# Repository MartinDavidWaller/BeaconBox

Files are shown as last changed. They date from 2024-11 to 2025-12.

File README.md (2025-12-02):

# BeaconBox - As published in Practical Wireless March 2025

BeaconBox - bringing life to the "YAESU THE RADIO AMATEUR's WORLD MAP"



## Modes

BeaconBox supports 3 three modes. The videos below demonstrate each one. 

### Beacons Heard Mode - Click on the image to launch the video.

(https://www.youtube.com/watch?v=FNRje14J34g)

### Beacons Active Mode - Click on the image to launch the video.

(https://www.youtube.com/watch?v=Vpn9oOLJUsw)

### Beacons In Daylight Mode - Click on the image to launch the video.

(https://www.youtube.com/watch?v=ngtQo7elz8o)

## Component list

Map and frame aside the following components will be required.

| Component | Quantity | Potential Source
| --- | --- | ---|
| Capacitor 100nf (104) | 24 |
| Capacitor 1nf | 1 |
| ESP32 WROOM-32 30 Pin | 1 | https://www.ebay.co.uk/itm/235648899105 See the image below. I have been sent some that simply say "ESP-32" on the top and they have failed. If you buy one from here and it does not say "ESP-MODULE-32" like the picture below I would return it. You should be able to see this before opening the protective wrapper.
| Misc' Hardware - Nuts & Bolts, PCB standoffs etc. These requirements will depend on your build. | * | 
| LED Holders 8mm | 18 | https://www.ebay.co.uk/itm/196322906972?var=496149156991
| PCB - Beacon LED Board | 18 |
| PCB - Frequencies Board | 1 |
| PCB - Processor Board | 1 |
| PCB Mount Terminal Block 3-Way | 2 |
| PCB Mount Terminal Block 2-Way | 2 | 
| Resistors 75 Ohm 1/4 Watt | 24 |
| Switch 6x6x5mm Momentary PCB Tactile | 2 |
| Wiring Loom | three different coloured wires, 3m of each | 
| WS2812D 8mm LEDs | 24 | https://www.ebay.co.uk/itm/134876658482

Not that the ESP32 WROON-32 30 Pin should look like:

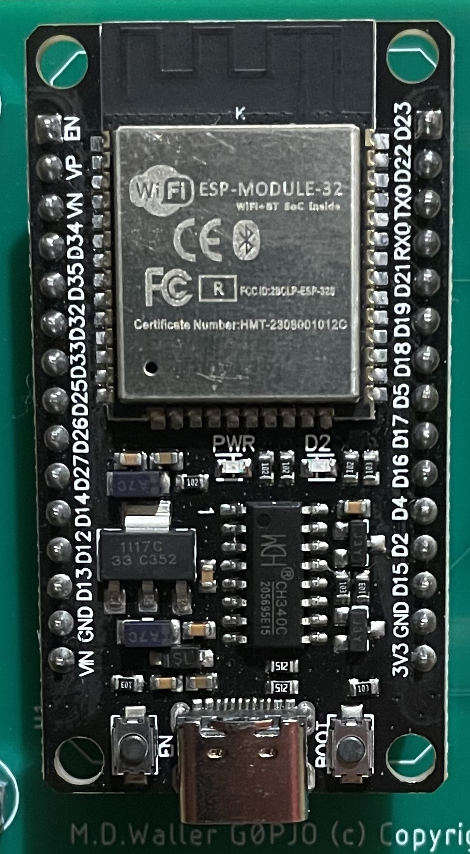
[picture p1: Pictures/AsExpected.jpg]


## Wiring the LEDs

The LEDS on the main board must be wired in the following order:

ZL6B, VK6RBP, JA2IGY, VR2B, 4S7B, RR90
4X6TU, 5Z4B, ZS6DN, OH2B, CS3B, VE8AT
W6WX, KH6RS, 4U1UN, YV5B, OA4B, and LU4AA

For more information about the 8mm LEDs see: https://www.electrokit.com/upload/product/41020/41020706/41020706.pdf

## Installing the software - See updates below

The source code for BeaconBox is not available. The software is distributed as a binary file
that can be downloaded directly to the ESP32 using esptool.exe that can be downloaded 
from https://github.com/espressif/esptool/releases. Download and install esptool.exe.

What follows is very specific to Microsoft Windows but similar tools and processes will apply
to MacOS etc.

Next connect the ESP32 to your computer using a USB cable. The device should appear as a COM port. 
You can use the Device Manager to identify thee new port - look for something called "USB-SERIAL CH340"
or similar. To be sure you have the correct COM port you could unplug it and see it dissapear and 
then plug it back in and see it appear. 

Next open a command window and type the command:

esptool.exe --chip esp32 --port COM4 --baud 921600 write_flash 0x0 BeaconBox_V0_8.bin

You may need to provide the complete path to the esptool.exe and you will probably need
to change COM4 to the COM port identified above.

## Issues

Please do not hesitate to contact me at martin@the-wallers.net is you have any problems.

## Updates

December 2nd, 2025 - Beacon_Box V0.8 Released

Changes

a) Update the help to specify tha a SPACE is needed between callsigns in the "Spotter Wildcards:".  
b) Fixed a bug where the updates of "Spotter Wildcards:" were not being acknowledged until the 
next reboot.

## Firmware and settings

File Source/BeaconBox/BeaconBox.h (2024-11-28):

/*
 *  BeaconBox.h
 *  
 *  Author:   M.D. Waller - G0PJO
 *  Copyright (c) 2024
 */

// The following manifests provide the product information

#define PROGRAM_NAME "BeaconBox"
#define PROGRAM_VERSION_MAJOR 0
#define PROGRAM_VERSION_MINOR 7
#define COPYRIGHT_TEXT "(C) M.D.Waller G0PJO"

// ----

#define REVERSE_BEACON_NETWORK_ADDRESS "telnet.reversebeacon.net"
#define REVERSE_BEACON_NETWORK_PORT 7000

#define DEFAULT_SPOTTER_WILDCARDS "G*"
#define DEFAULT_TIMEZONE "GMT0BST,M3.5.0/01,M10.5.0/02"

#define DEFAULT_SPOTTER_TIMEOUT_MINUTES 5
#define DEFAULT_FREQUENCY_STEP_TIME_SECONDS 5
#define DEFAULT_LED_BRIGHTNESS 255

// The mode pin must support pullout. See https://forum.arduino.cc/t/esp32-pins-that-support-pullup/1173356/3

#define MODE_PIN 25

// LEDs - two LED types are supported WS2812B and WS2812D (8mm)

#define LED_TYPE_WS2812B 1
#define LED_TYPE_WS2812D 2

// Supported Builds

#define BUILD_TYPE_TEST_BOARD 1
#define BUILD_TYPE_YAESU_MAP 2

#define BUILD_TYPE BUILD_TYPE_YAESU_MAP

#if BUILD_TYPE == BUILD_TYPE_TEST_BOARD

  #define LED_TYPE LED_TYPE_WS2812B
    
#elif BUILD_TYPE == BUILD_TYPE_YAESU_MAP

  #define LED_TYPE LED_TYPE_WS2812D
#else

  #error BUILD_TYPE - Unrecognised value.
#endif

// Define the animation defaults

#define DEFAULT_ANIMATION_ENABLED true
#define DEFAULT_ANIMATION_BEACONS_HEARD_DURATION_SECONDS 30
#define DEFAULT_ANIMATION_BEACONS_ACTIVE_DURATION_SECONDS 30
#define DEFAULT_ANIMATION_BEACONS_IN_DAYLIGHT_DURATION_SECONDS 10
#define DEFAULT_ANIMATION_MANUAL_MODE_TIMEOUT_SECONDS 60

// The following enumeration is used to control the operation mode

typedef enum {
  
  OPERATION_MODE_BEACONS_HEARD,     // Usual mode, reporting beacons that have been heard
  OPERATION_MODE_NCDXF_IARU,        // NCDXF/IARU Transmission schedule mode
  OPERATION_MODE_DAYLIGHT           // Daylight mode
  
} OPERATION_MODE;

// The following are used to control DEBUG output

#define DEBUG_BEACONS_IN_DAYLIGHT 1
#define DEBUG_SCAN_SSIDS 1

// Defined methods / data

extern OPERATION_MODE activeMode;

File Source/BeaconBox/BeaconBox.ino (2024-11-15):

/*
 *  BeaconBox.ino
 *  
 *  Author:   M.D. Waller - G0PJO
 *  Copyright (c) 2024
 */

 /*
  * Issues:
  * 
  * When returning SSIDs we need to provide a proper name without spaces etc so the load of the options works? Or
  * at least that's what I think is making it fail.
  * 
  * Make use of DEFAULT_BEACON_TIMEOUT_MINUTES.
  * 
  * https://mapsvg.com/maps/world
  * 
  * Map from https://www.fla-shop.com/svg/
  */

  /*
   * EAGLE PCB Libraries
   * 
   * ESP32 - 30 Pin - https://github.com/shridattdudhat/ESP32-DEVKITV1
   * ESP32 - 38 Pin - https://hackaday.io/project/46280/files             DevKitC
   */

  /*
   * Read all the flash
   * 
   * C:\Users\marti>C:\Users\marti\AppData\Local\Arduino15\packages\esp32\tools\esptool_py\4.6/esptool.exe --chip esp32 --port COM4 --baud 921600 read_flash 0 ALL flash_contents.bin
   * 
   * Erase all the flash
   * 
   * C:\Users\marti>C:\Users\marti\AppData\Local\Arduino15\packages\esp32\tools\esptool_py\4.6/esptool.exe --chip esp32 --port COM4 --baud 921600 erase_flash
   * 
   * Write flash
   * 
   * C:\Users\marti>C:\Users\marti\AppData\Local\Arduino15\packages\esp32\tools\esptool_py\4.6/esptool.exe --chip esp32 --port COM4 --baud 921600 write_flash 0x0 flash_contents.bin
   */
   
#include "Arduino.h"

#include <FastLED.h>
#include "SPIFFS.h"
#include <WiFi.h>

#include "Animation.h"
#include "BeaconBox.h"
#include "Beacons.h"
#include "Configuration.h"
#include "Dump.h"
#include "LEDChain.h"
#include "Errors.h"
#include "RBNClient.h"
#include "WebServer.h"

// The following manifests are used to control the active state

typedef enum {
  
  //STATE_BUILDING_ACCESS_POINT,
  STATE_CONNECTING_TO_WIFI,
  STATE_CONNECTING_TO_REVERSE_BEACON_NETWORK,
  STATE_RECIEVING_RBN_DATA
  
} RUNNING_STATE;

// Define the working data

struct Configuration configuration;               // Configuration object
OPERATION_MODE activeMode;                        // Active mode
OPERATION_MODE requestedMode;                     // Requested mode, changed by the mode switch
RUNNING_STATE currentState;                       // Current running state
time_t startUpTime;                               // Startup time

boolean startAP() {

  #define START_AP_DELAY 1000
  
  // Start the Access Point
  
  boolean result = WiFi.softAP(PROGRAM_NAME);

  // Return the result
  
  return result;
}  

void stepTheMode() {

  switch(activeMode) {

    case OPERATION_MODE_BEACONS_HEARD:
      requestedMode = OPERATION_MODE_NCDXF_IARU;
      break;
        
    case OPERATION_MODE_NCDXF_IARU:
      requestedMode = OPERATION_MODE_DAYLIGHT;
      break;
        
    case OPERATION_MODE_DAYLIGHT:
      requestedMode = OPERATION_MODE_BEACONS_HEARD;
      break;

    default:
      break;
  }  
}

void IRAM_ATTR switchInterrupt() {

  static unsigned long last_interrupt_time = 0;

  // Get the interrupt time
  
  unsigned long interrupt_time = millis();
  
  // Is it 200 ms greater than the last interrupt, if not ignore it
  
  if (interrupt_time - last_interrupt_time > 200) 
  {
    // Update the requested mode depending on the active node. Basically
    // switch it between the available modes

    stepTheMode();

    // Tell the animation

    animationManualEvent();
  }

  // Update the last interrupt time
  
  last_interrupt_time = interrupt_time;
}

void configurationUpdateHandler() {

  // Pass on any change to the LED brightness

  ledBrightness(configuration.LEDBrightness);
}

void modeChangeHandler(bool manualEvent) {

  // If this is a manual event then we may need to step the mode

  if (true == manualEvent) {

    // Tell the animation about the manual event
    
    animationManualEvent();
  }
  
  // Step the moode

  stepTheMode();

  // If this is not a manual event then it must be an animation event. The
  // problem we have now is that the the mode we have stepped to might be
  // one with a zero duration. We need to check for this and move on if
  // that is the case. The thing we do know is that at leat two modes
  // have none zero durations so if we find we have a zero duration then
  // simply moving on again will correct it!

  if (false == manualEvent) {
    
    switch(requestedMode) {

      case OPERATION_MODE_BEACONS_HEARD:

        if (0 == configuration.BeaconsHeardDurationSeconds) {
          requestedMode = OPERATION_MODE_NCDXF_IARU;
        }
        break;
        
      case OPERATION_MODE_NCDXF_IARU:

        if (0 == configuration.BeaconsActiveDurationSeconds) {
          requestedMode = OPERATION_MODE_DAYLIGHT;
        }
        break;
        
      case OPERATION_MODE_DAYLIGHT:
    
        if (0 == configuration.BeaconsInDaylightDurationSeconds) {
          requestedMode = OPERATION_MODE_BEACONS_HEARD;
        }   
        break;

      default:
        break;
    }  
  }
}

// This is the setup routine. It all starts here.

void setup() {

  // Set up the serial port so we can generate debug etc.
  
  Serial.begin(115200);\
  while (!Serial) {
    ; // wait for serial port to connect. Needed for native USB port only
  } 

  Serial.printf("%s V%d.%d - Up and running", PROGRAM_NAME, PROGRAM_VERSION_MAJOR, PROGRAM_VERSION_MINOR);
  
  // Set up the mode button

  pinMode(MODE_PIN,INPUT_PULLUP);

  // Set the active mode and requested mode to the default

  activeMode = OPERATION_MODE_BEACONS_HEARD;
  requestedMode = OPERATION_MODE_BEACONS_HEARD;

  // Setup the LEDs and put on a short display.

  ledChainSetUp();

  // Setup the errors

  errorsSetUp();
  
  // Read the configuration data from the EEPROM

  Serial.println("");
  Serial.println("Read the Configuration Data");
  bool checkSumOK = readConfiguration(&configuration);

  //Serial.println("");
  //hexDump((char *)&configuration,sizeof(Configuration));

  // If the checksum is not OK or if the version numbers
  // do not match then we must start again!

  if ((false == checkSumOK) || 
      (configuration.MajorVersion != PROGRAM_VERSION_MAJOR) || 
      (configuration.MinorVersion != PROGRAM_VERSION_MINOR) ||
      (0 == digitalRead(MODE_PIN))) {

    // Here the versions don't match or the checksum is wrong or
    // the boot pin is pressed.

    if (false == checkSumOK) {
      Serial.println("");
      Serial.println("Invalid checksum.");       
    }
    else if ((configuration.MajorVersion != PROGRAM_VERSION_MAJOR) || 
             (configuration.MinorVersion != PROGRAM_VERSION_MINOR)) {

      // Report the difference in version numbers

      Serial.printf("Different verison numbers. Found V%d.%d, Expected V%d.%d\n",
        configuration.MajorVersion,
        configuration.MinorVersion,
        PROGRAM_VERSION_MAJOR,
        PROGRAM_VERSION_MINOR
        );
    }
    else {
      Serial.println("");
      Serial.println("Reset switch active.");      
    }
      
    // Initialise the configuration data

    memset(&configuration,0,sizeof(Configuration));
    configuration.MajorVersion = PROGRAM_VERSION_MAJOR;
    configuration.MinorVersion = PROGRAM_VERSION_MINOR;
    strcpy((char*)&configuration.Hostname[0],PROGRAM_NAME);
    strcpy((char*)&configuration.TimeZone[0],DEFAULT_TIMEZONE);
    strcpy((char*)&configuration.SpotterWildcards[0],DEFAULT_SPOTTER_WILDCARDS);
    configuration.SpotterTimeOutMinutes = DEFAULT_SPOTTER_TIMEOUT_MINUTES;
    configuration.FrequencyStepTimeSeconds = DEFAULT_FREQUENCY_STEP_TIME_SECONDS;
    configuration.LEDBrightness = DEFAULT_LED_BRIGHTNESS;

    configuration.AnimationEnabled = DEFAULT_ANIMATION_ENABLED;
    configuration.BeaconsHeardDurationSeconds = DEFAULT_ANIMATION_BEACONS_HEARD_DURATION_SECONDS;
    configuration.BeaconsActiveDurationSeconds = DEFAULT_ANIMATION_BEACONS_ACTIVE_DURATION_SECONDS;
    configuration.BeaconsInDaylightDurationSeconds = DEFAULT_ANIMATION_BEACONS_IN_DAYLIGHT_DURATION_SECONDS;
    configuration.ManualModeTimeoutSeconds = DEFAULT_ANIMATION_MANUAL_MODE_TIMEOUT_SECONDS;

    Serial.println("Writing new configuration");
    Serial.println("");
    hexDump((char *)&configuration,sizeof(Configuration));

    // Write it out
    
    writeConfiguration(&configuration); 

    // Next we need to setup the access point.
  }

  // Dump the current configuration
  
  dumpConfiguration(&configuration);    

  // We are going to need access to the files stored so start up SPIFFS
  // and list out what we have.

  Serial.println("");
  Serial.println("Contents of SPIFFS:");
  Serial.println("");

  if(false == SPIFFS.begin(true)) {

    // Tell the user 
    
    Serial.println("SPIFFS Mount Failed");

    // Display the error

    errorOpeningSpiffs();
    return;
  }

  // Blink the LEDs

  ledBrightness(configuration.LEDBrightness);
  ledChainBlinkAll();
    
  // Open the root object
  
  File root = SPIFFS.open("/");

  // Loop through the files
  
  File file = root.openNextFile();
  while (file) {
    if (true == file.isDirectory()) {
      Serial.print("  DIR : ");
      Serial.println(file.name());    
    } else {
      Serial.printf("  FILE: %s %d\n", file.name(), file.size());
    }

    // Move to the next file
    
    file = root.openNextFile();
  }  

  // Set the time server

  configTime(0, 0, "pool.ntp.org");
  setenv("TZ", (char*)&configuration.TimeZone[0],1);

  // Set the start time

  time(&startUpTime);
  
  // Next start the Access Point

  bool accessPointStarted = startAP();
  if (false == accessPointStarted) {

    // Tell the user 
    
    Serial.println("");
    Serial.println("Failed to start the access point!");

    // Display the error

    errorOpeningAccessPoint();
  }
  else
  {
    // Display the local IP address
    
    IPAddress ipAddress = WiFi.softAPIP();
    Serial.printf("\nLocal Access Point IP: http://%s\n",ipAddress.toString().c_str());
  }

  // Setup the interrupt service routine

  attachInterrupt(MODE_PIN, switchInterrupt, FALLING);
  
  // Setup the beacons

  beaconsSetUp(&configuration.SpotterWildcards[0]);

  // Next setup the Web Server

  webServerSetUp(&configurationUpdateHandler, &modeChangeHandler);

  // Next setup the animation

  animationSetUp(&modeChangeHandler);

  // Set the current state

  currentState = STATE_CONNECTING_TO_WIFI;  
}

void connectToWiFi() {
  
  // We are about to connect to the WiFi. We need to ensure that we
  // have the necessary data to try.

  if (0 == strlen((char *)&configuration.WiFi_SSID[0])) {

    // We don't currently have a SSID, display the error

    errorSettingsRequired();
  }
  else {

    // We have a SSID, etc try to make the connection

    /*
     * If you do disconnect here then the user is thrown off the access point.
     * 
     * Disconnect anything that we may have
     *
     * WiFi.disconnect();
     */

    // Apply any hostname that we may have. If we done have one then we
    // can default it to the program name

    Serial.printf("\nSetting hostname: %s\n",(char *)&configuration.Hostname[0]);
    if (strlen((char *)&configuration.Hostname[0]) > 0)
      WiFi.setHostname((char *)&configuration.Hostname[0]);
    else
      WiFi.setHostname(PROGRAM_NAME);    
        
    // Begin the connection
  
    WiFi.begin((char *)&configuration.WiFi_SSID[0],(char *)&configuration.WiFi_Password[0]);

    // Disable sleep
  
    WiFi.setSleep(false);
    
    // Wait for the connection to be made.

    int maxTry = 10;
    while ((WiFi.status() != WL_CONNECTED) && (maxTry > 0)) {

      // Wait and update the try count.

      delay(1000);
      maxTry--;
    }

    // Did we manage to connect?

    if (WiFi.status() != WL_CONNECTED) {

      // Here the connection has failed

       Serial.printf("\nConnected to WiFi failed!\n");

       // Display the error

       errorConnectingToWiFi();
    }
    else {

      // Here we are connected to the WiFi

      IPAddress ipAddress = WiFi.localIP();

      Serial.printf("\nConnected to WiFi: http://%s\n",ipAddress.toString().c_str()); 
      
      // Kick off a WiFi Scan, we may need the SSID list later.

      WiFi.scanNetworks(true);

      // Move to the next state
          
      currentState = STATE_CONNECTING_TO_REVERSE_BEACON_NETWORK;
    }
  }
}

void spotHandler(char *spotter, char*spotted, double frequency, char *rbnType, char *rbnTime) {

  //Serial.printf("spotHandler: spotter: %s, spotted %s, frequency %f, type %s, time %s\n", spotter, spotted, frequency, rbnType, rbnTime); 

  sendToRBNDataListeners(spotter, spotted, frequency, rbnType, rbnTime);
}

time_t lastBeaconsHeard = -1;

void doBeaconsHeardMode() {

  // Here we are displaying beacons that have been heard.
  
  // We need to decide if the time is right to step on to the
  // next beacon frequency

  // Get the time
  
  time_t timeNow;
  time(&timeNow);

  // Is it time to update the beacons frequency?
  
  if ((-1 == lastBeaconsHeard) || (timeNow > lastBeaconsHeard + configuration.FrequencyStepTimeSeconds)) {

    // Yes, step the beacons
    
    dumpBeacons();
    beaconsStepBeacon();

    // Update the time of the last step
    
    time(&lastBeaconsHeard);
  }
}

time_t lastBeaconsActive = -1;

void doBeaconsActiveMode() {

  // Here we are displaying beacons that are active.
  
  // We need to decide if the time is right to move on

  // Get the time
  
  time_t timeNow;
  time(&timeNow);

  // Is it time to update the beacons frequency?
  
  if ((-1 == lastBeaconsActive) || (timeNow > lastBeaconsActive + 1)) {

    // Yes, update the active beacons
    
    beaconsShowActiveBeacons();

    // Update the time of the last step
    
    time(&lastBeaconsActive);
  }
}

time_t lastDaylight = -1;

void doDaylightMode() {

  // Here we are displaying beacons that are in daylight.
  
  // We need to decide if the time is right to move on

  // Get the time
  
  time_t timeNow;
  time(&timeNow);

  // Is it time to update the beacons in daylight
  
  if ((-1 == lastDaylight) || (timeNow > lastDaylight + 5 * 60)) {

    // Yes, update the beacons in daylight
    
    beaconsShowBeaconsInDaylight();

    // Update the time of the last step
    
    time(&lastDaylight);
  }
}

void loop() {
  
  // What we do here depend on what state we are in.

  switch(currentState) {

    case STATE_CONNECTING_TO_WIFI:

      // Make the connection to the WiFi
      
      connectToWiFi();
      break;

    case STATE_CONNECTING_TO_REVERSE_BEACON_NETWORK:

      // Make sure that we are connected to the WiFi

      if (WiFi.status() != WL_CONNECTED)
      {
        // Revert to connecting to the WiFi
        
        currentState = STATE_CONNECTING_TO_WIFI;
      }
      else
      {
        // Try connecting to the Reverse Beacon Network

        bool connected = rbnClientConnect(REVERSE_BEACON_NETWORK_ADDRESS, REVERSE_BEACON_NETWORK_PORT, spotHandler);

        if (true == connected) {

          Serial.printf("\nConnected to RBN %s:%d\n",REVERSE_BEACON_NETWORK_ADDRESS, REVERSE_BEACON_NETWORK_PORT); 

          // Update the current state to receiving RBN data
        
          currentState = STATE_RECIEVING_RBN_DATA;     

          // Update the animation start time
          
          animationStart();
        }
        else {

          // Not connected

           Serial.printf("\nFailed to connect to RBN %s:%d\n",REVERSE_BEACON_NETWORK_ADDRESS, REVERSE_BEACON_NETWORK_PORT); 
        }
      }
        
      break;    

    case STATE_RECIEVING_RBN_DATA:

      // Have we changed mode?

      if (activeMode == requestedMode) {

        // No change, decode the active mode and action it

        switch(activeMode) {
          case OPERATION_MODE_BEACONS_HEARD:

            doBeaconsHeardMode();
            break;
            
          case OPERATION_MODE_NCDXF_IARU:

            doBeaconsActiveMode();
            break;
            
          case OPERATION_MODE_DAYLIGHT:

            doDaylightMode();
            break;
        }

        // Process any animation

        animationAnimate();
      }
      else {

        // Here we have a change of mode!

        // Clear all frequency LEDs before moving on

        ledTurnOffAllFrequencyLeds();

        // What's changing

        switch(requestedMode) {
          
          case OPERATION_MODE_BEACONS_HEARD:

            // Usual mode, reporting beacons that have been heard. All we
            // need to do is reset the timer.

            lastBeaconsHeard = -1;
            break;
            
          case OPERATION_MODE_NCDXF_IARU:

            // NCDXF/IARU Transmission schedule mode

            // Clear down all beacons LED

            ledTurnOffAllBeaconLeds();
          
            // Reset the time

            lastBeaconsActive = -1;
          
            // Set the frequency colours
          
            beaconsShowFrequencyColours();

            // Clean up all beacons

            clearActiveBeaconColours();
            sendAllBeaconsOffToBeaconListeners();         
            break;
            
          case OPERATION_MODE_DAYLIGHT:

            // Reset the time

            lastDaylight = -1;
            
            // Turn off all the frequency leds
            
            ledTurnOffAllFrequencyLeds();

            // Ditto on any webpage

            clearActiveBeaconColours();
            sendAllFrequenciesOffToBeaconListeners();
            break;          
        }
        
        // Finally make this the active mode

        activeMode = requestedMode;
      }
      
      // Whatever mode we are in we need to process any data that we have received
      // from the reverse beacon network.
      
      bool stillConnected = rbnClientProcessData((char*)&configuration.Callsign[0]);

      // Are we still connected?

      if (false == stillConnected) {

        // No, update the state

        currentState = STATE_CONNECTING_TO_REVERSE_BEACON_NETWORK;
      }

      break;        
  }

  // This delay is important. It stops other threads being starved
  // of CPU time.
  
  delay(1) ;
}

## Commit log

2024-09-27 New files.
    [Configuration.h]
2024-09-27 Code changes
    [Configuration.h]
2024-10-03 More files, more code.
    [Configuration.h]
2024-10-09 Added LED Flash
2024-10-12 Moved to the board
2024-10-16 More changes
    [Configuration.h]
2024-10-30 Help update and frequency step time interface.
    [Configuration.h]
2024-10-31 More changes.
    [Configuration.h]
2024-11-01 Small PCB
    [WS2812D.brd]
2024-11-03 More PCB
    [BOM.xlsx, DRILEGEND.CFG, ESP32 30Pin Large Map.brd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]
2024-11-28 Started changes for the map board!
2024-11-30 Rename Source to Source Old to save confusion.
    [Configuration.h]
2024-12-01 Tidy up
    [A4-B_Cu.gbl, A4-B_Cu.gbr, A4-B_Mask.gbr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]
2025-02-12 Added picture of ESp32
